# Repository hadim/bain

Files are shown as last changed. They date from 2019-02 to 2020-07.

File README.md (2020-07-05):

# Bain



A DIY IoT wireless sensor for temperature, humidity and pressure. It is made of two parts:

- [Adafruit Feather HUZZAH with ESP8266](https://www.adafruit.com/product/2821): it's an Arduino compatible board that has WiFi capability and a connector to plug any Adafruit 3.7V Lithium polymer batteries. Note that any ESP8266 board should work.
- [Adafruit BME280 I2C or SPI](https://www.adafruit.com/product/2652): It's an environmental sensor with temperature, barometric pressure and humidity from Bosch.

This repository contains all the instructions to build the Bain sensor yourself.

## Features

- 🌡 Monitor **temperature**, **pressure** and **humidity**.
- ✈ Data are sent to a custom **MQTT** broker as a **JSON** string.
- 🕕 **Time is syncronized** every 6h with NTP and the **timezone** can be specified.
- 😴 Deep sleep mode can be enabled to **reduce power consumption**. A standard LiPo battery of [1200 mAh](https://www.adafruit.com/product/258) can last about a week. Consumption is ~6.5mA while in deep sleep mode (optional).
- 🔋 Monitor **battery level** (optional).
- 💡 The source code is profusely commented and factorized. It should be **easy to adapt** to your needs.

## Instructions

### Assembly on a breadboard

Follow the connections shown below. There is 4 connections (blue, red, yellow and green) in between the Feather ESP8266 board the BME280 chip. And also a last connection in purple to enable deep sleep mode and reduce battery consumption (optional).

**Warning:** Apparently, the Feather ESP8266 chip can't be flashed with the purple connection so you have to disconnect it, then flash and then reconnect it.

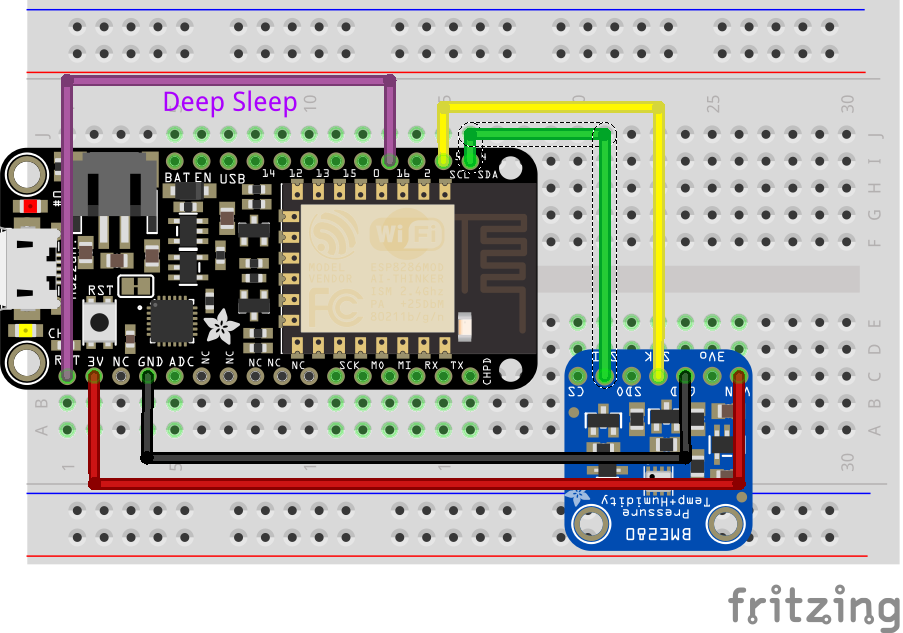
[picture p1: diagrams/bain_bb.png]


### Flash the controller

#### Environement Setup

You should use the [Arduino IDE](https://www.arduino.cc/en/main/software) to flash the controller to the board. Note that [a VSCode extension for Arduino IDE](https://marketplace.visualstudio.com/items?itemName=vsciot-vscode.vscode-arduino) is also available and works well.

- You need to add the following URL to the **Arduino Board Manager**: `http://arduino.esp8266.com/stable/package_esp8266com_index.json`.

- Then in the **Arduino Board Manager**, install the `ESP8266` package. After this, you should be able to select the correct board from the **Board Manager**: `Adafruit Feather HUZZAH ESP8266`.

- Then you need to install the following Arduino libraries (use the **Arduino Library Manager**):

  - [Adafruit ESP8266](https://github.com/adafruit/Adafruit_ESP8266): Arduino board with WiFi capability.
  - [Adafruit BME280 Library](https://github.com/adafruit/Adafruit_BME280_Library): Sensor library.
  - [Adafruit Unified Sensor](https://github.com/adafruit/Adafruit_Sensor): Needed for Adafruit BME280 Library.
  - [ArduinoJson](https://github.com/bblanchon/ArduinoJson): a JSON library.
  - [NTPClient](https://github.com/arduino-libraries/NTPClient): an NTP client library to get date and time.

#### Controller Configuration

- Configure WiFi and MQTT credentials:

  - Copy `bain/secret.h.template` to `bain/secret.h`.
  - Edit `bain/secret.h`.

```cpp
#ifndef BAIN_SECRET
#define BAIN_SECRET

#define WIFI_SSID "myssid"
#define WIFI_PASSWORD "mypassword"

#define MQTT_SERVER "your_server"
#define MQTT_PORT 1883
#define MQTT_CLIENT_ID "sensor1"
#define MQTT_MESSAGE_TOPIC "/bain_sensor/1"

// Leave blank to disable auth.
#define MQTT_USERNAME "your_username"
#define MQTT_PASSWORD "your_password"

#endif
```

- Configure other parameters by editing `bain/parameters.h`.

```cpp
#ifndef BAIN_PARAMETERS
#define BAIN_PARAMETERS

// Timezone
const int timeOffsetHours = -5;

// Delay between two measures in seconds.
const int loop_delay_s = 60;

// Enable deep sleep mode.
const boolean deep_sleep = true;

// Monitor battery level.
const boolean monitorBattery = true;

// LEDs. Disable by setting value to `-1`.
// Warning: Unused at the moment.
const int state_LED = -1;

#endif
```

#### Upload Firmware

Now you're ready to flash the controller.

- From you editor, open [`bain/bain.ino`](bain/bain.ino).
- Compile it.
- After connecting the board to your computer, upload the controller.

By reading on the serial port, you should see logging messages about WiFi, the sensor and also the JSON string sent to the MQTT broker:

```json
{
  "temperature": 25.23,
  "pressure": 1018.4,
  "humidty": 90.12,
  "timestamp": "2019-02-15 15:45:23",
  "batteryLevel": 82.3,
  "batteryCharging": false,
  "batteryVoltage": 3.76
}
```

### Battery Level Monitoring

If you want to monitor the LiPo battery level, you need to add some connections to your circuit as shown below. For this you need the following parts:

- 1 x 10 kΩ resistor
- 1 x 47 kΩ resistor
- 1 x 1 MΩ resistor
- 1 x 1 µF capacitor

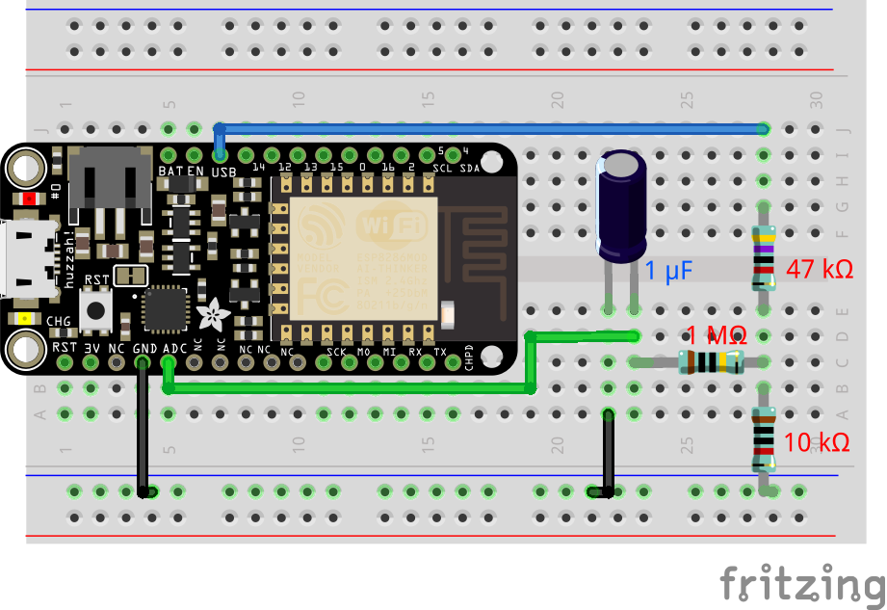
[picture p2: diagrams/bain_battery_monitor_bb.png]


Then you need to set `monitorBattery` to `true` in `bain/parameters.h`.

_This setup comes from https://github.com/lobeck/adafruit-feather-huzzah-8266-battery-monitor._

### Final Assembly

Once you've checked your assembly works you can solder everything together using a [FeatherWing proto board](https://www.adafruit.com/product/2884). Here is the final assembly diagram:

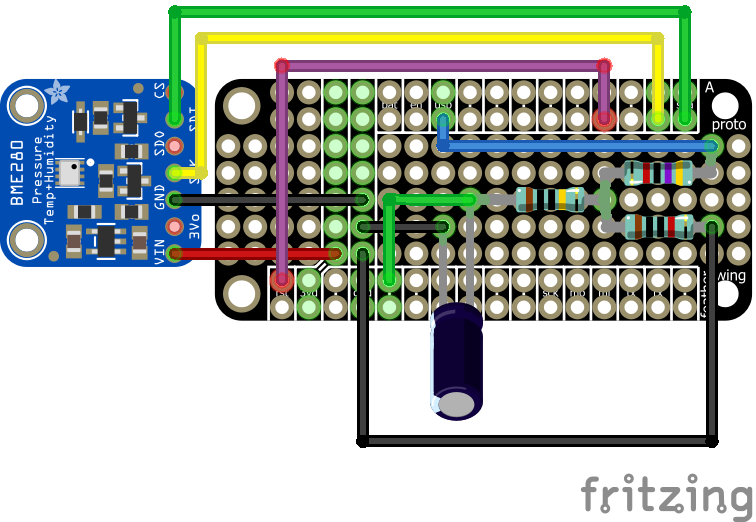
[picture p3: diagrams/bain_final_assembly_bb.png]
Bain Final Assembly


## Case

**TODO.**

## Home Assistant

If your MQTT broker is connected to an [Home Assistant](https://www.home-assistant.io) instance, Bain sensors should be automatically discovered.

## License

[MIT](./LICENSE).

## Author

- [Hadrien Mary](mailto:hadrien.mary_AT_gmail.com)

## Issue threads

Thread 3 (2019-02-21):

Disable LED during wake up

hadim, 2019-02-21:

hadim, 2019-02-21:
According to this: https://www.reddit.com/r/esp8266/comments/4rduea/is_there_a_way_to_use_software_to_disable_the_led/d50dow8/

it does not seem to be that important to save energy.

hadim, 2019-02-21:
There is another LED that can be disabled: https://openhomeautomation.net/esp8266-battery

Not sure I have it on the ESP8266 from Adafruit...

hadim, 2019-02-21:
Nice thread too: https://forums.adafruit.com/viewtopic.php?f=8&t=120675

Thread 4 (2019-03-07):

How to make the battery last longer

hadim, 2019-03-07:
See https://community.home-assistant.io/t/bain-a-diy-iot-wireless-sensor-for-temperature-humidity-and-pressure/99691

and also https://forums.adafruit.com/viewtopic.php?f=8&t=120675&start=15

hadim, 2019-03-07:
Interesting too: https://openhomeautomation.net/esp8266-battery

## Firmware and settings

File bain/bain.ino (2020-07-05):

#include "parameters.h"
#include "secret.h"
#include "wifi.h"
#include "sensor.h"
#include "mqtt.h"
#include "ntp.h"
#include "battery.h"

#include <ArduinoJson.h>

// MQTT
const String mqtt_message_topic_base = MQTT_MESSAGE_TOPIC_BASE;

// WiFi
const char *wifi_ssid = WIFI_SSID;
const char *wifi_password = WIFI_PASSWORD;

// Suggested rate is 1/60Hz (1 m or 60,000 ms)
const int loop_delay_ms = loop_delay_s * 1000;

void setup()
{
    Serial.begin(115200);
    while (!Serial)
        ;

    // Clean console.
    Serial.println("");

    // Init BME280 sensor.
    initBME280Sensor();

    // Connect to WiFi and print some informations
    // about the connection.
    connectWifi(wifi_ssid, wifi_password);
    logWifiInformations();

    // Init NTP
    initNTP();

    if (deep_sleep == true)
    {
        one_step();
        disconnectMQTT();
        disconnectWifi();
        ESP.deepSleep(loop_delay_ms * 1e3);
    }
}

void loop()
{
    if (deep_sleep == false)
    {
        one_step();
        delay(loop_delay_ms);
    }
}

void one_step()
{
    // Update time if needed.
    updateNTP();

    // Check in case WiFi has been disconnected.
    connectWifi(wifi_ssid, wifi_password);

    // Get a timestamp.
    String timestamp = getTimeStampString();

    // Measure battery level
    BatteryLevel batteryLevel;
    if (monitorBattery)
    {
        batteryLevel = measureBatteryLevel();
    }

    // Get sensor values.
    //SensorValues sensorValues;
    SensorValues sensorValues = getSensorValues();

    // Send configs to MQTT broker
    sendConfig(sensorValues, batteryLevel);

    // Send state to MQTT broker
    sendState(sensorValues, batteryLevel, timestamp);
}

void sendConfig(SensorValues sensorValues, BatteryLevel batteryLevel)
{
    // Prepare message
    const size_t capacity = JSON_OBJECT_SIZE(3) + JSON_OBJECT_SIZE(10) + 360;
    DynamicJsonDocument data(capacity);

    String measurement_name = "Temperature";
    String measurement_type = "temperaturepppp";
    String measurement_unit = "°C";
    String measurement_template = "{{ value_json.temperature | round(1) }}";
    String entity_name = device_id + "_" + measurement_type;

    data["name"] = measurement_name;
    data["device_class"] = measurement_type;
    data["unit_of_measurement"] = measurement_unit;
    data["platform"] = "mqtt";
    data["force_update"] = true;
    data["expire_after"] = 0;

    // Example: "/homeassistant/sensor/bain/living_room/state"
    data["state_topic"] = mqtt_message_topic_base + "/" + device_id + "/state";

    // Example: "{{ value_json.temperature }}"
    data["value_template"] = measurement_template;

    // Example: "/bain/living_room/temperature"
    data["unique_id"] = entity_name;

    JsonObject device = data.createNestedObject("device");
    device["name"] = sensor_name;
    device["manufacturer"] = sensor_manufacturer;
    device["identifiers"] = device_id;
    device["sw_version"] = sensor_version;

    // Send message

    // Example: "/bain/living_room/temperature"
    String message_topic = mqtt_message_topic_base + "/" + device_id;
    message_topic = message_topic + "/" + entity_name + "/config";

    String message = "";
    serializeJson(data, message);
    sendMessage(message, message_topic, true);
}

void sendState(SensorValues sensorValues, BatteryLevel batteryLevel, String timestamp)
{
    // Prepare message
    const size_t capacity = JSON_OBJECT_SIZE(7) + 90;
    DynamicJsonDocument data(capacity);

    if (sensorValues._valid)
    {
        data["temperature"] = sensorValues.temperature;
        data["pressure"] = sensorValues.pressure;
        data["humidity"] = sensorValues.humidity;
    }
    else
    {
        data["temperature"] = "";
        data["pressure"] = "";
        data["humidity"] = "";
    }

    if (batteryLevel._valid)
    {
        data["batteryLevel"] = batteryLevel.level;
        data["batteryCharging"] = batteryLevel.isCharging;
        data["batteryVoltage"] = batteryLevel.realVoltage;
    }
    else
    {
        data["batteryLevel"] = "";
        data["batteryCharging"] = "";
        data["batteryVoltage"] = "";
    }

    const char *timestampChar = timestamp.c_str();
    data["timestamp"] = timestampChar;

    // Send message

    // Example: "/bain/living_room/temperature"
    String message_topic = mqtt_message_topic_base + "/" + device_id + "/state";

    String message = "";
    serializeJson(data, message);
    sendMessage(message, message_topic, true);
}

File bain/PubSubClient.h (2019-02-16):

/*
 PubSubClient.h - A simple client for MQTT.
  Nick O'Leary
  http://knolleary.net
*/

#ifndef PubSubClient_h
#define PubSubClient_h

#include <Arduino.h>
#include "IPAddress.h"
#include "Client.h"
#include "Stream.h"

#define MQTT_VERSION_3_1 3
#define MQTT_VERSION_3_1_1 4

// MQTT_VERSION : Pick the version
//#define MQTT_VERSION MQTT_VERSION_3_1
#ifndef MQTT_VERSION
#define MQTT_VERSION MQTT_VERSION_3_1_1
#endif

// MQTT_MAX_PACKET_SIZE : Maximum packet size
#ifndef MQTT_MAX_PACKET_SIZE
#define MQTT_MAX_PACKET_SIZE 512
#endif

// MQTT_KEEPALIVE : keepAlive interval in Seconds
#ifndef MQTT_KEEPALIVE
#define MQTT_KEEPALIVE 15
#endif

// MQTT_SOCKET_TIMEOUT: socket timeout interval in Seconds
#ifndef MQTT_SOCKET_TIMEOUT
#define MQTT_SOCKET_TIMEOUT 15
#endif

// MQTT_MAX_TRANSFER_SIZE : limit how much data is passed to the network client
//  in each write call. Needed for the Arduino Wifi Shield. Leave undefined to
//  pass the entire MQTT packet in each write call.
//#define MQTT_MAX_TRANSFER_SIZE 80

// Possible values for client.state()
#define MQTT_CONNECTION_TIMEOUT -4
#define MQTT_CONNECTION_LOST -3
#define MQTT_CONNECT_FAILED -2
#define MQTT_DISCONNECTED -1
#define MQTT_CONNECTED 0
#define MQTT_CONNECT_BAD_PROTOCOL 1
#define MQTT_CONNECT_BAD_CLIENT_ID 2
#define MQTT_CONNECT_UNAVAILABLE 3
#define MQTT_CONNECT_BAD_CREDENTIALS 4
#define MQTT_CONNECT_UNAUTHORIZED 5

#define MQTTCONNECT 1 << 4      // Client request to connect to Server
#define MQTTCONNACK 2 << 4      // Connect Acknowledgment
#define MQTTPUBLISH 3 << 4      // Publish message
#define MQTTPUBACK 4 << 4       // Publish Acknowledgment
#define MQTTPUBREC 5 << 4       // Publish Received (assured delivery part 1)
#define MQTTPUBREL 6 << 4       // Publish Release (assured delivery part 2)
#define MQTTPUBCOMP 7 << 4      // Publish Complete (assured delivery part 3)
#define MQTTSUBSCRIBE 8 << 4    // Client Subscribe request
#define MQTTSUBACK 9 << 4       // Subscribe Acknowledgment
#define MQTTUNSUBSCRIBE 10 << 4 // Client Unsubscribe request
#define MQTTUNSUBACK 11 << 4    // Unsubscribe Acknowledgment
#define MQTTPINGREQ 12 << 4     // PING Request
#define MQTTPINGRESP 13 << 4    // PING Response
#define MQTTDISCONNECT 14 << 4  // Client is Disconnecting
#define MQTTReserved 15 << 4    // Reserved

#define MQTTQOS0 (0 << 1)
#define MQTTQOS1 (1 << 1)
#define MQTTQOS2 (2 << 1)

// Maximum size of fixed header and variable length size header
#define MQTT_MAX_HEADER_SIZE 5

#if defined(ESP8266) || defined(ESP32)
#include <functional>
#define MQTT_CALLBACK_SIGNATURE std::function<void(char *, uint8_t *, unsigned int)> callback
#else
#define MQTT_CALLBACK_SIGNATURE void (*callback)(char *, uint8_t *, unsigned int)
#endif

#define CHECK_STRING_LENGTH(l, s)                \
   if (l + 2 + strlen(s) > MQTT_MAX_PACKET_SIZE) \
   {                                             \
      _client->stop();                           \
      return false;                              \
   }

class PubSubClient : public Print
{
 private:
   Client *_client;
   uint8_t buffer[MQTT_MAX_PACKET_SIZE];
   uint16_t nextMsgId;
   unsigned long lastOutActivity;
   unsigned long lastInActivity;
   bool pingOutstanding;
   MQTT_CALLBACK_SIGNATURE;
   uint16_t readPacket(uint8_t *);
   boolean readByte(uint8_t *result);
   boolean readByte(uint8_t *result, uint16_t *index);
   boolean write(uint8_t header, uint8_t *buf, uint16_t length);
   uint16_t writeString(const char *string, uint8_t *buf, uint16_t pos);
   // Build up the header ready to send
   // Returns the size of the header
   // Note: the header is built at the end of the first MQTT_MAX_HEADER_SIZE bytes, so will start
   //       (MQTT_MAX_HEADER_SIZE - <returned size>) bytes into the buffer
   size_t buildHeader(uint8_t header, uint8_t *buf, uint16_t length);
   IPAddress ip;
   const char *domain;
   uint16_t port;
   Stream *stream;
   int _state;

 public:
   PubSubClient();
   PubSubClient(Client &client);
   PubSubClient(IPAddress, uint16_t, Client &client);
   PubSubClient(IPAddress, uint16_t, Client &client, Stream &);
   PubSubClient(IPAddress, uint16_t, MQTT_CALLBACK_SIGNATURE, Client &client);
   PubSubClient(IPAddress, uint16_t, MQTT_CALLBACK_SIGNATURE, Client &client, Stream &);
   PubSubClient(uint8_t *, uint16_t, Client &client);
   PubSubClient(uint8_t *, uint16_t, Client &client, Stream &);
   PubSubClient(uint8_t *, uint16_t, MQTT_CALLBACK_SIGNATURE, Client &client);
   PubSubClient(uint8_t *, uint16_t, MQTT_CALLBACK_SIGNATURE, Client &client, Stream &);
   PubSubClient(const char *, uint16_t, Client &client);
   PubSubClient(const char *, uint16_t, Client &client, Stream &);
   PubSubClient(const char *, uint16_t, MQTT_CALLBACK_SIGNATURE, Client &client);
   PubSubClient(const char *, uint16_t, MQTT_CALLBACK_SIGNATURE, Client &client, Stream &);

   PubSubClient &setServer(IPAddress ip, uint16_t port);
   PubSubClient &setServer(uint8_t *ip, uint16_t port);
   PubSubClient &setServer(const char *domain, uint16_t port);
   PubSubClient &setCallback(MQTT_CALLBACK_SIGNATURE);
   PubSubClient &setClient(Client &client);
   PubSubClient &setStream(Stream &stream);
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

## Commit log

2019-02-07 Add cntroller with sensor and wifi code.
2019-02-07 add led state
2019-02-08 Start assembling. Sensor does not work
    [bain.fzz]
2019-02-10 flash sensor 2
2019-02-10 better readme
    [bain.fzz]
2019-02-10 add battery monitoring
2019-02-12 fix message length issue
    [PubSubClient.h]
2019-03-02 work on battery ,onitoring
2019-03-02 add esp32
2019-03-06 Add final assembly
    [bain.fzz, bain_battery_monitor.fzz, bain_final_assembly.fzz]
2019-03-07 Better diagrams and update README
    [bain.fzz, bain_battery_monitor.fzz, bain_final_assembly.fzz]
2019-03-08 Handle missing sensor and missing batter monitoring assembly.
    [bain.ino, battery.h]
2019-03-08 Switch back to &à retry for sensor init.
2019-03-08 Init sensor before init wifi.
2019-03-10 Fix wrong connections for sensor.
    [bain.fzz, bain_final_assembly.fzz]
2019-03-10 Return 100% battery when plugged
